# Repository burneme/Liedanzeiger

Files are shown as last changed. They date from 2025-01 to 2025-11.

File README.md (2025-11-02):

# St. Martin, Liedanzeiger #

Many of the old-fashion displays in churches face problems when searching for spare parts i.e. bulbs and resting switches. I found a very nifty way to do a replacement using "https://github.com/mrazekv/church-numbers",
where a system with HDMI-Monitor and raspberry-Pi zero 2W is shown as a solution.
The invest is very small, currently used 24"-Monitors (in most cases this size is more than enough) are cheap, a "raspberry pi zero 2W" is less than 20€ and the input can be done with any browser on tablet/mobile-phone/notebook.

The minium you need is:

  **Full HD-Monitor** with HDMI input,
  
  **raspberry pi zero W** or **raspberry pi zero W** including **µSD-card 8GB minimum**,
  
  **tablet / mobile phone / PC / notebook**,
  
  **HDMI cable** and a **USB-power supply**.

This material can be conveniently sourced in Europe from berrybase.de or similar suppliers. Even optional material, shown in a separate directory, is available there.
  
The code for the µSD card "ready to start" you can get in the meanwhile from this site. It was my first intention to provide the final image to avoid the nasty work for people who are not trained to linux. You might use the link from mrazekv including all the steps to get a rocksolid installation (read-only file system). Github doesn't allow large files, even my available cloud cannot handle files beyond 1GB, so google helped me. See the link below the pictures.
If there is the requirement for one or more additional displays (side aisles), a Sat(telite) version is possible. In cases, when the second monitor is not far away, a HDMI-splitter can be used to connect two monitors to one single raspberry. In my home town this unit with satellite is now running for a year with good experience.

Finally it looks like this:

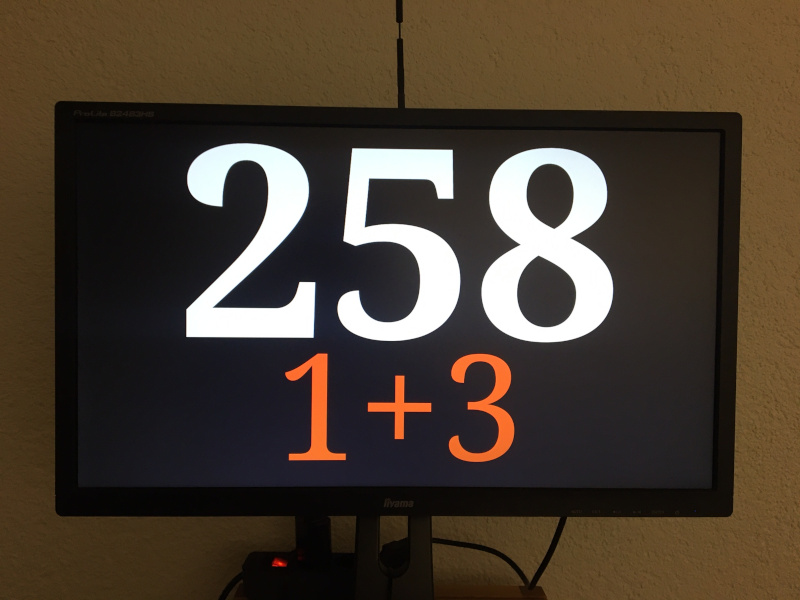
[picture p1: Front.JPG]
Front

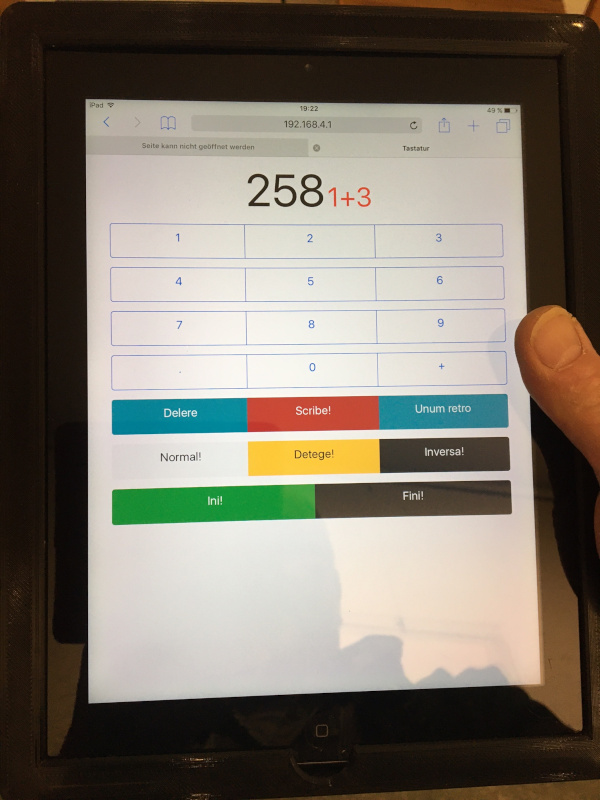
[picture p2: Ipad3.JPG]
ipad3


ipad3 with a printed frame to hook it on the organists console

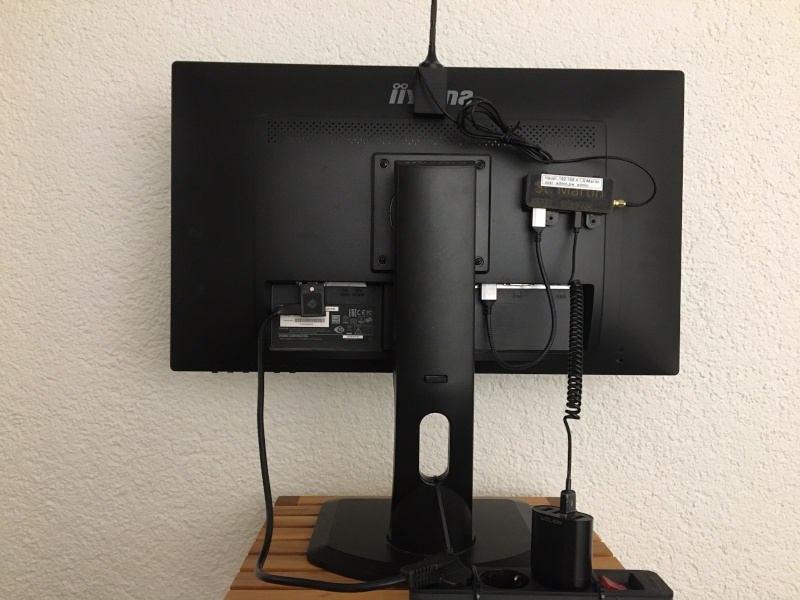
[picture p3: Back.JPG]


Neat arrangement of connection cables.

## Creating a working SD-card ##

Finally I found a download space for the image at google:

[Click here to download image for Single Display](https://drive.google.com/file/d/1Por2zFch3SOl4XRDp1puK9v_BIOZQSrb/view?usp=drive_link/ "An raspberry pi zero image for one display") 

When the download is complete, you need to flash a sd-card using "belena etcher", download this if you don't have it installed already and start it.

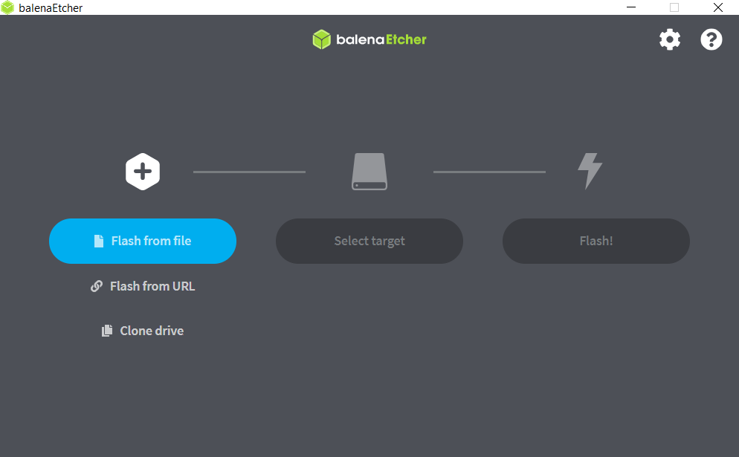
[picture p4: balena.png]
BalenaFlasher


When you have  the finished card, insert this into the slot of raspberry pi zero and apply power, the already operating monitor should show for a second a colored pattern followed by a spinner. When the spinner disapears, you should be able to connect to a Wifi-net called "StMartin", you will be asked for the password "Epiphany". The system gives your device an IP-adress in the net 192.168.4.0.
The next step is to call the index.html, insert into your favourite browser "192.168.4.1" as the URL and press enter, the entry mask should appear.
You can enter a three-digit main number and a substring followed by "Scribe!" (Write!), "Detege!" clears the display.

>  ## Password change ##
>
>  The password for the wifi-net inside the given image is "Epiphany", you should change that as soon as you can. Change this asap, otherwise you will end in a musical request concert :).
>
>  This pw is stored in /etc/hostapd/hostapd. To change it, you need to connect to the system.
>
>  For linux, beeing in the same network, use
>
>  **ssh admin@192.168.4.1**
> (for windows install "putty" before)
>
>  you answer with "admin" and get the message "connected to..."
>
> Change to the subdirectory
> 
>  **admin@raspberrypi(ro):~$** *cd /etc/hostapd*
>
>  Since you are in a read-only mode, you need to switch to read-write-mode:
>
>  **admin@raspberrypi(ro):/etc/hostapd$** *rw*
>
>  Then call the editor (i use joe, behaves like old wordstar) 
>
>  **admin@raspberrypi(rw):/etc/hostapd$** *sudo joe hostapd.conf* 
>
>  Change the pw accordingly to your personal requests.
>
>  To store it, type 
>  **cntl-k**
>  and 
>  **x**,
>
>  then set back to read-only:
>
>  **admin@raspberrypi(rw):/etc/hostapd$** *ro*
>
>  reboot (replug) and use your new wifi pw.

The small changes for a second system, acting as a slave, will follow on request.
Have fun and distribute it.

**P.S.:**

**Issues during operation**

After nearly one year we faced a problem with difficult reception, the system could not recognize commands and did not react. The cause was a noisy USB power supply. Changing this to and old one from the surplus, it worked fine again. Since the noisy one was brandnew (1year old) from China, it might be a reason why your setup is not working as expected. It seems that the raspberry is not very resistant to noisy supplies.
If you can, use a supply recommended for raspberry Pi which is sold usually as a set. **Furthermore the disassembled faulty supply did not show any clear seperation/isolation space from mains to output. Unclear how this unit can pass any VDE or UL test or inspection.**

Attached see the output voltage of the faulty supply (AC-Coupling, 20mV/div):

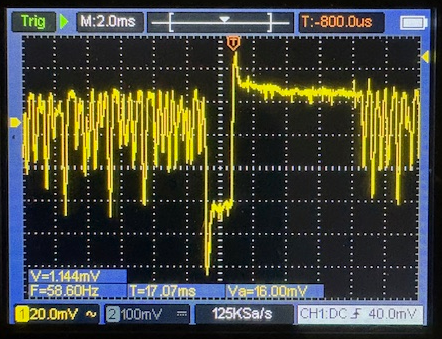
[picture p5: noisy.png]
Faulty supply voltage


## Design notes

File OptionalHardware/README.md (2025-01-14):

| | picture | source: < sourcing keyword > | comment | 
|:--- |:---:|:---:|:---:|
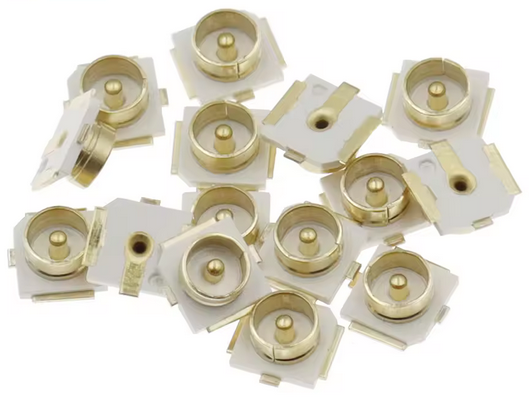
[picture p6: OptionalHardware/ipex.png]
| <span class="text-nowrap"><i class="fa fa-leaf fa-fw"></i> **socket**</span> ||aliexpress or berrybase: <ipex 2mm>|This IPEX socket (2mm) is required if you don't want to use the internal raspberry antenna. You should have good eyes or microsope. A tiny copper trace need to be cut. Make a test wether the standard is sufficient before you start to solder|
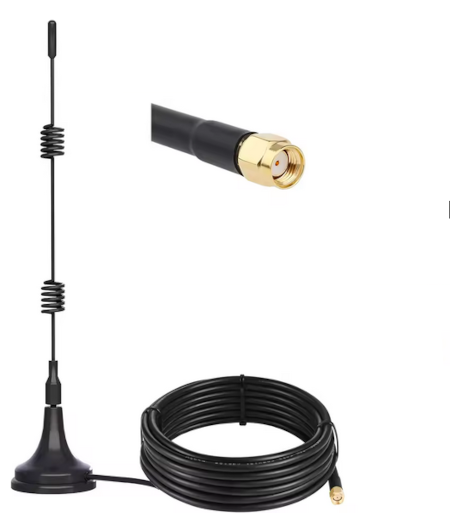
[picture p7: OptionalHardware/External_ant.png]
| <span class="text-nowrap"><i class="fa fa-leaf fa-fw"></i> **antenna**</span> ||aliexpress or berrybase: <2.4GHz Antenna, SMA>|Prefere a wired antenna with magnetic base, you will be in a better position when you do operating range tests! Possibly you'll find an old router antenna from the bargain bin.|
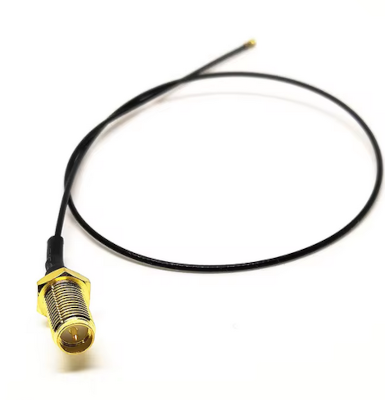
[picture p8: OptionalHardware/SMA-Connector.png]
| <span class="text-nowrap"><i class="fa fa-leaf fa-fw"></i> **SMA-Con**</span> ||aliexpress or berrybase: < RP-SMA or SMAtoIPEX >|Depending on the antennas socket, you need female or male connector. 5cm length should be enough. Pls. check before you order.|
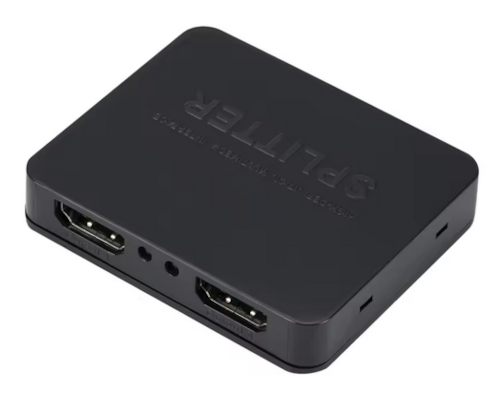
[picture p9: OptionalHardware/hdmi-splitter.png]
| <span class="text-nowrap"><i class="fa fa-leaf fa-fw"></i> **HDMI-Splitter**</span> ||aliexpress: < HDMI-Splitter >|You need this to double the output of the HDMI-Port of raspberry in order to connect two monitors in parallel. Requires an USB-Power connection.|

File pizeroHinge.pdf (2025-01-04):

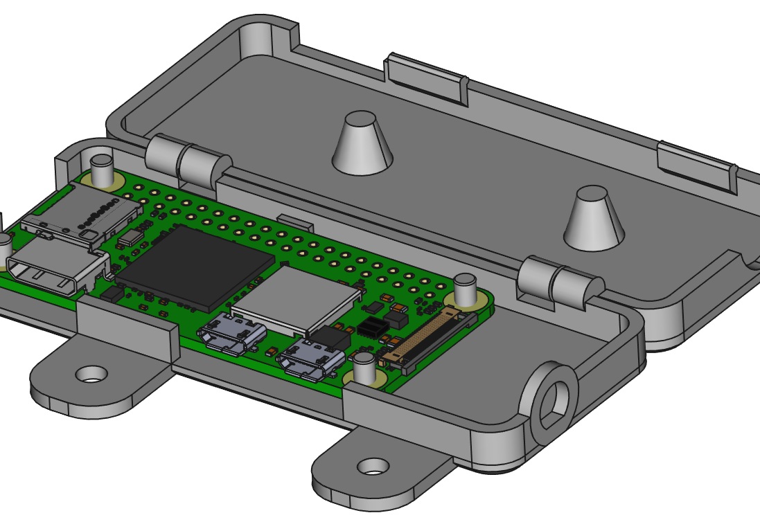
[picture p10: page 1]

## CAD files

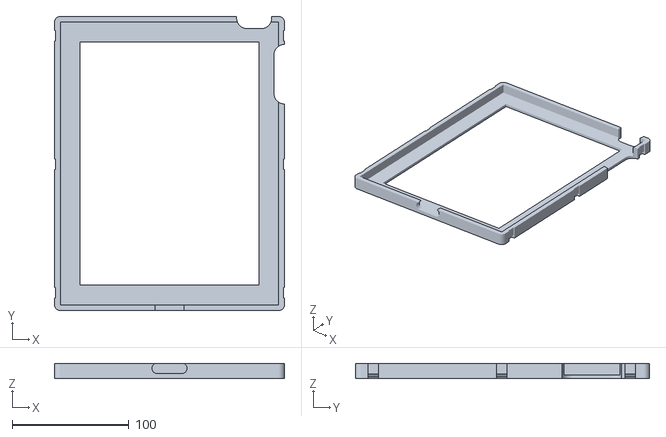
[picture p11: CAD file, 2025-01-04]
ipad3R2-Cut001.stl
197.0 x 252.0 x 12.5

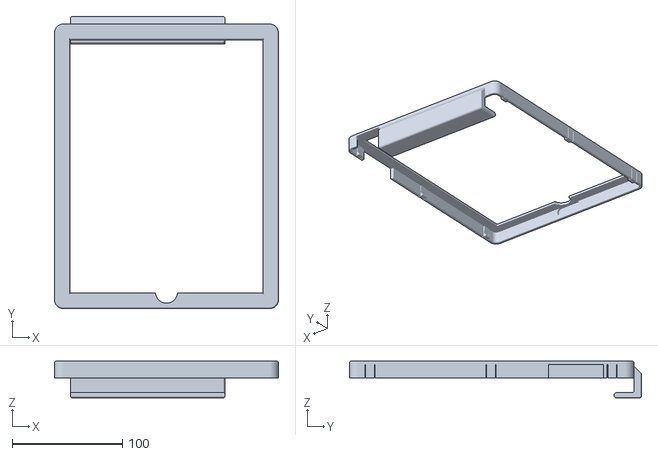
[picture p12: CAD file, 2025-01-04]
ipad3R2-Cut002.stl
203.5 x 265.5 x 33.5

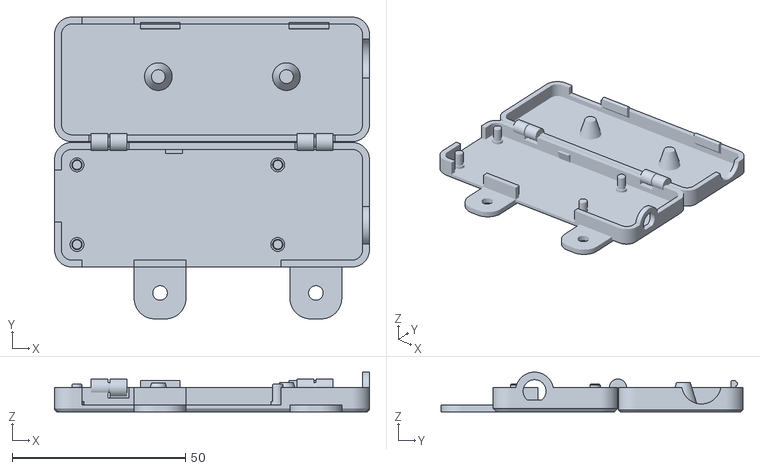
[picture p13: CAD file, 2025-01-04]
PiZeroHinge-Cut004.stl
91.0 x 87.2 x 11.5

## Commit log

2025-01-04 A self printable housing for the raspberry pi
    First design with printed hinges and a hole for SMA-connector.
2025-01-04 STL-data for the pizero housing
    If you have a 3d-printer, don't hesitate!
    [PiZeroHinge-Cut004.stl]
2025-01-04 ipad3 enclosure for 3d-printing
    This is a frame for ipad3 which can be hooked in the organs book holder. The ipad itself is to slippery.
    [ipad3R2-Chamfer001.stl, ipad3R2-Cut002.stl]
2025-01-04 Stl for 3D-printing
    other half to ipad3R2-Cut001
    [ipad3R2-Cut001.stl]
2025-11-02 Document issues with USB power supply in README
    Added notes about issues with noisy USB power supply affecting system performance.
2025-11-02 Update README with power supply issues and recommendations
    Clarified issues with power supply affecting system performance and added details about faulty supply inspection.
